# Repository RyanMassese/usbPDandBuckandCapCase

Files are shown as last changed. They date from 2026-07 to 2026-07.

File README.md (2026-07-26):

# USB-C PD + Buck Converter + Capacitor Case

3D-printable enclosure (STL) for a small USB-C-powered adjustable DC supply
built from:

| Component | Part | Envelope used |
|---|---|---|
| DC-DC buck module 3–40 V in / 1.5–35 V out | [Altronics Z6334](https://www.altronics.com.au/p/z6334-dc-dc-buck-module-3-40v-input/) (LM2596) | 43 × 21 × 14 mm |
| 1000 uF 50 V low-ESR electrolytic capacitor | [Altronics R6187](https://www.altronics.com.au/p/r6187-lelon-1000uf-50v-pcb-low-esr-electrolytic-capacitor/) | 17 mm dia × 33 mm |
| USB-C PD trigger board, selectable voltage | [Core Electronics CE08536](https://core-electronics.com.au/usb-c-pd-trigger-board-selectable-voltage.html) | 42 × 18 mm |

A second **storage variant** additionally holds a BP-511 dummy battery
(DC coupler, 55 × 38 × 21 mm) and ~2 m of coiled cable.

## Files

Compact (electronics only), external **60.8 × 68.3 × 23.3 mm**:

- `case_base.stl` — the box. Print as-is (flat bottom on the bed).
- `case_lid.stl` — the lid, modeled in its assembled orientation.
- `case_lid_print_orientation.stl` — same lid pre-flipped flat-top-down, ready to print.
- `case_assembly_preview.stl` — base + lid together, for visual checking only.

With storage section, external **148.6 × 68.3 × 31.3 mm** (two-part lid):

- `case_base_with_storage.stl` — the box.
- `case_lid_with_storage_electronics.stl` — screwed lid over the electronics
  section (3 × M3).
- `case_lid_with_storage_hatch.stl` — tool-free snap-fit hatch over the
  battery/cable storage section.
- `case_lid_with_storage_electronics_print_orientation.stl`,
  `case_lid_with_storage_hatch_print_orientation.stl` — pre-flipped to print.
- `case_assembly_with_storage_preview.stl` — visual check only.

Shared:

- `generate_case.py` — parametric generator; edit dimensions and re-run to regenerate everything.

## Layout

The lane order and orientation follow how the unit is actually soldered: the
capacitor **and** the output cable go straight onto the buck module's
OUT+/OUT− pads with short leads, and flying leads run from the PD board's
screw terminal to the buck's IN pads. So the buck sits IN-end-first beside the
PD board's terminal — a ~24 mm hop for the input pair — which puts OUT at the
USB-C end with the capacitor's lead end right beside it.

Three parallel bays separated by 10 mm divider walls. **Each divider stops
short at the end where soldered wires have to cross lanes**, so nothing has to
arch over a wall:

1. **PD trigger bay** (front) — board slides in against the end wall; a
   14 × 9.6 mm cutout in that wall accepts the USB-C plug overmold. An end
   stop holds the board with 0.5 mm play. A 26 × 10 mm window in the lid
   exposes the voltage-select button and its LED row. The last 14 mm of the
   lane past the board is left open as a loop zone for the input pair, and
   the PD/buck divider is cut away there.
2. **Buck module bay** (middle) — low corner stops locate the 43 × 21 mm
   board with its **IN end toward the loop zone**. Lid vent slots (3 mm wide)
   sit above it for cooling and double as screwdriver access, but set the
   output voltage with the trimpot **before** final assembly. The output
   cable leaves through an 8 mm slot in the OUT-end wall (open to the top
   edge), one lane over from the USB-C opening.
3. **Capacitor cradle** (back) — the 1000 uF cap lies on its side in two
   saddle ribs (17.5 mm dia opening) with its **lead end toward the buck's
   OUT end**, about 16 mm of lead path away. The buck/cap divider is cut away
   for the first 16 mm so the leads cross straight over.

Because the input and output both terminate at the buck's OUT end, the USB-C
socket and the DC output slot share the same end wall, ~25 mm apart. That is
forced by the wiring: putting the PD terminal next to the buck's IN end
necessarily puts the USB-C and the output at the other.

### Storage variant

The storage version is 26.5 mm deep inside (vs 18.5 mm): the BP-511 dummy is
~21 mm thick lying flat, and its cable enters through a hole in the dummy's
**top face**, so there is ~5.5 mm of headroom for the cable to bend over the
battery. The section sits right of the electronics, behind a full-height
wall:

The bays follow the cable's own order — it arrives from the electronics, gets
coiled, and ends at the dummy — so the coil bay comes first and the BP-511
sits at the outer end beside the slot it deploys through:

4. **Cable bay** — open 44 × 63.5 × 26.5 mm compartment (~74 cm³) for ~2 m of
   coiled cable, first thing past the section wall. Because the output cable
   is soldered at the buck's OUT end (the USB-C end), it runs back over the
   top of the buck module and through a **high** notch in that wall — there
   is 12.5 mm of headroom above the module in this variant.
5. **BP-511 pocket** — 40 × 56 mm pocket at the outer end, behind a 12 mm
   retaining rib. The rib is well under the dummy's 21 mm thickness, so its
   top-face cable simply passes over into the bay; the rib's 26 mm gap is
   finger access to lift the dummy out.
6. **Deployment slot** — an 8 mm slot in the outer end wall beside the stored
   dummy, at the opposite end of the case from the USB-C inlet. It is open to
   the top edge: with the hatch off, lift the dummy out over the wall, drop
   its cable into the slot, and snap the hatch back on with the unused length
   still coiled inside.

The lid is split in two at the section wall:

- **Electronics lid** — screwed down with the same 3 × M3 self-tappers as the
  compact case. You only open this for wiring changes.
- **Storage hatch** — no screws. A half-round snap ridge on each long edge of
  its lip clicks into matching grooves in the case walls (~0.25 mm
  engagement). Thumb notches in both wall top edges, centered on the storage
  section, let you push the hatch edge up to pop it off. Snap tightness is
  tuned via `SNAP_RIDGE_R` / `SNAP_GROOVE_R` in the script.

## Assembly

1. Print in PETG or PLA, 0.2 mm layers, 3 walls, no supports needed
   (the USB-C opening bridges 14 mm — any printer handles that).
2. Set the buck module's output voltage first, then drop the boards in.
   A dab of hot glue or double-sided tape under each board stops rattle.
3. Orientation matters — the bays are cut for one way round:
   - PD board: USB-C against the end wall, screw terminal facing in.
   - Buck module: **IN end away from the USB-C wall**, OUT end toward it.
   - Capacitor: **lead end toward the USB-C wall**, beside the buck's OUT
     pads (mind polarity — the stripe is negative).
4. The input pair crosses the cut-away PD/buck divider at the IN end; the
   cap leads and the output cable cross the cut-away buck/cap divider at the
   OUT end. Nothing needs to route over a divider.
5. Lid screws: 3 × M3 self-tapping (8–10 mm long) into the corner posts
   (2.7 mm pilot holes), countersunk heads sit flush.

## Regenerating / tweaking

```bash
pip install trimesh manifold3d shapely numpy
python3 generate_case.py
```

All dimensions (wall thickness, clearances, bay sizes, slot positions) are
named parameters at the top of `generate_case.py`.

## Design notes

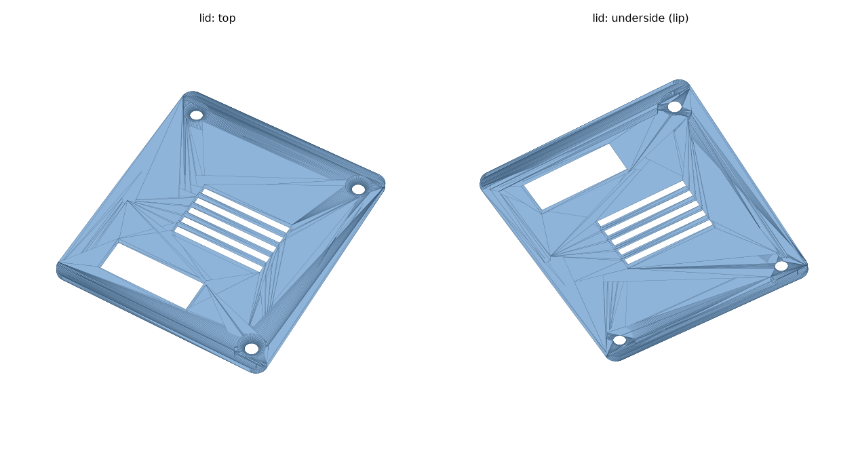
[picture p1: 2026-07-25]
preview_lid.png

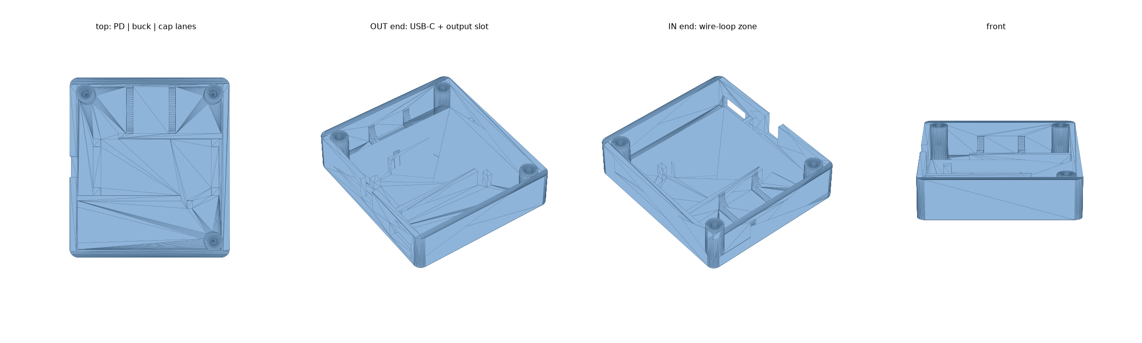
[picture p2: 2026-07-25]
preview_base.png

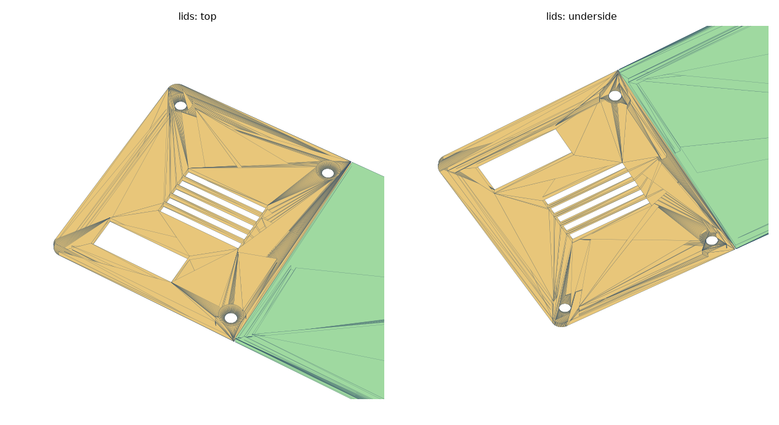
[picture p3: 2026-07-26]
preview_lid_with_storage.png

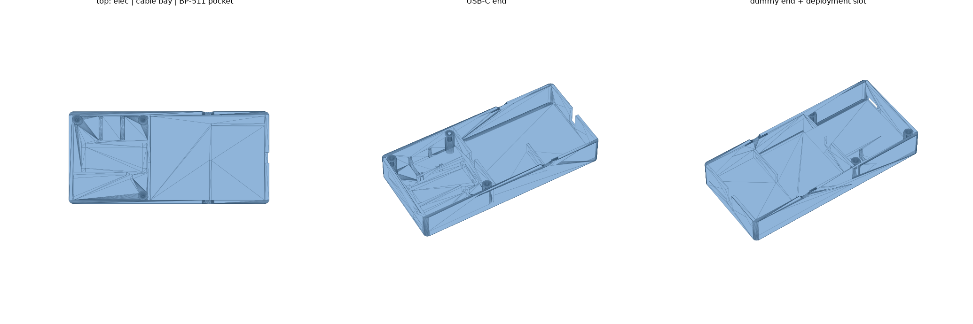
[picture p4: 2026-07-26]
preview_base_with_storage.png

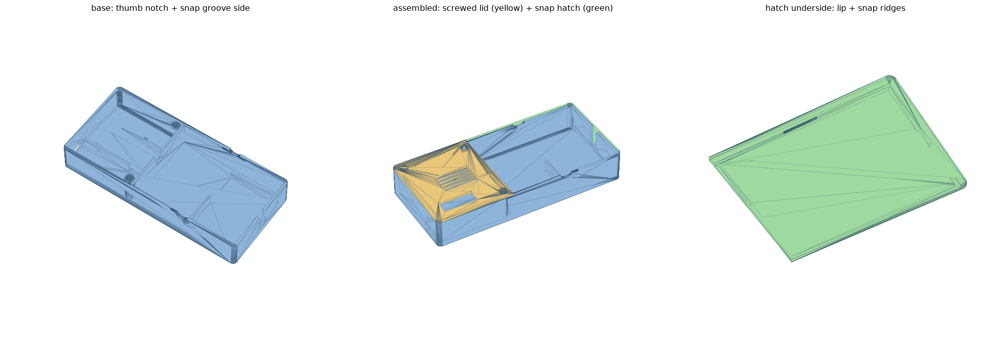
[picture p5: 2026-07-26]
preview_split_lid.png

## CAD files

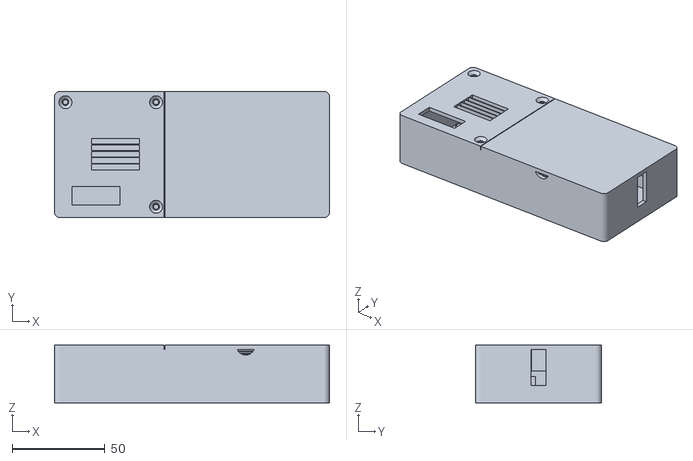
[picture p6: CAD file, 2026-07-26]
case_assembly_with_storage_preview.stl
148.6 x 68.3 x 31.3

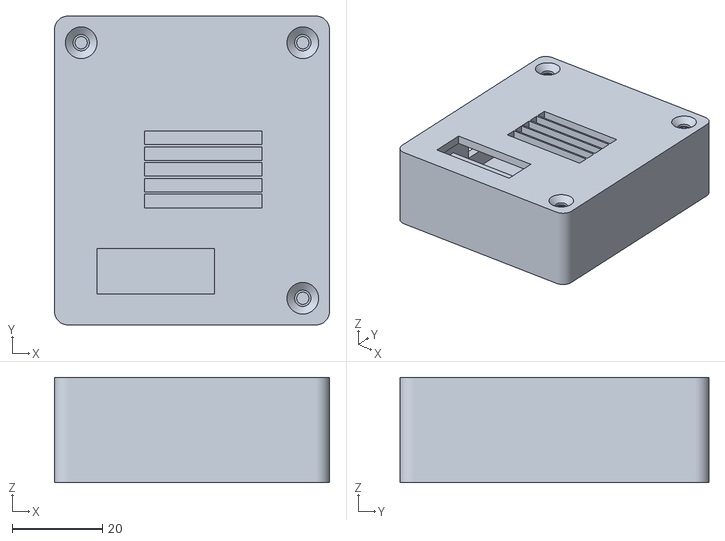
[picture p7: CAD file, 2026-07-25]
case_assembly_preview.stl
60.8 x 68.3 x 23.3

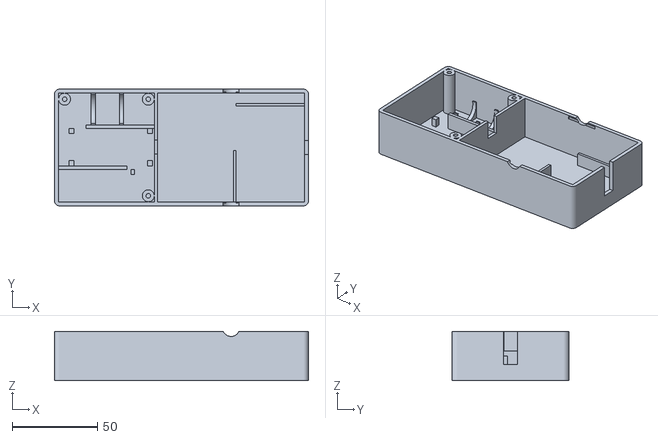
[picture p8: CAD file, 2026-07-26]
case_base_with_storage.stl
148.6 x 68.3 x 28.9

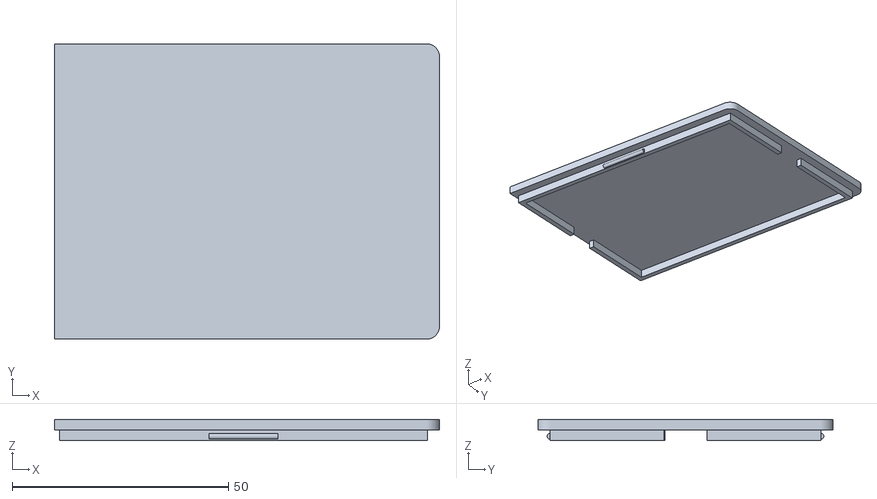
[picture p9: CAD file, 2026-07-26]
case_lid_with_storage_hatch.stl
89.0 x 68.3 x 4.90

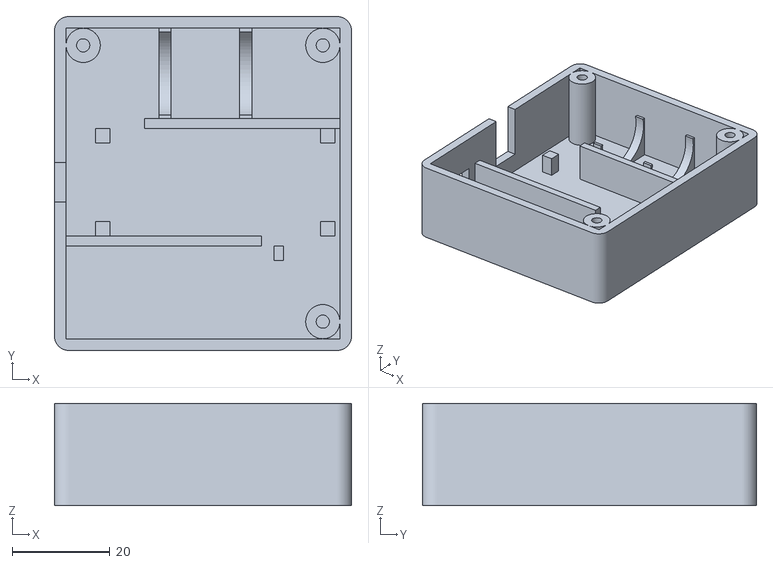
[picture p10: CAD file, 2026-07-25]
case_base.stl
60.8 x 68.3 x 20.9

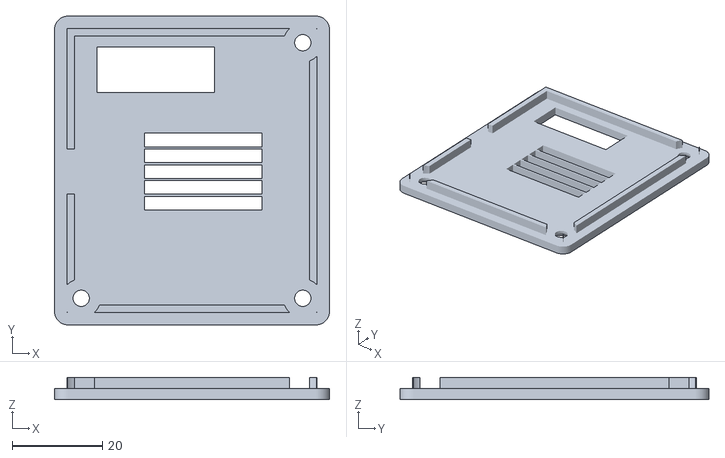
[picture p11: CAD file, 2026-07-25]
case_lid_print_orientation.stl
60.8 x 68.3 x 4.90

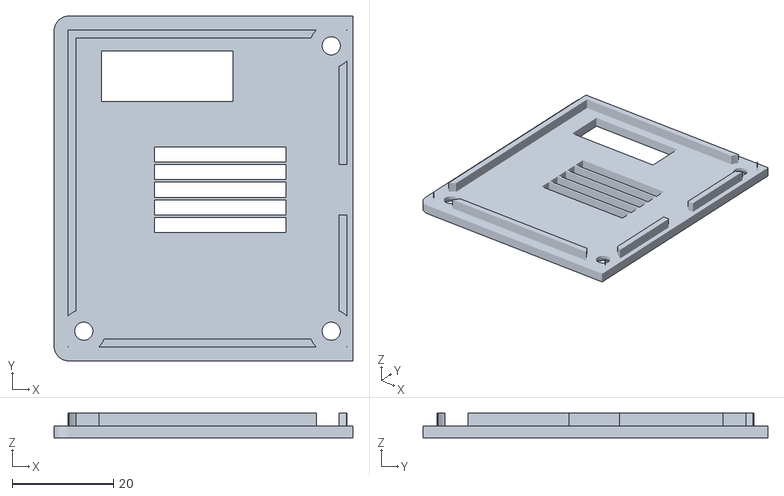
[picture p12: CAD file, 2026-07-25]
case_lid_with_storage_electronics_print_orientation.stl
59.2 x 68.3 x 4.90

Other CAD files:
case_lid_with_storage_hatch_print_orientation.stl
case_lid_with_storage_electronics.stl
case_lid.stl

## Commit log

2026-07-25 Add 3D-printable case for USB-C PD trigger, buck module and capacitor (#1)
    Parametric generator and STLs for two enclosure variants: compact electronics-only, and a version with a storage section for a BP-511 dummy battery and 2m of coiled cable.
    [case_assembly_preview.stl, case_assembly_with_storage_preview.stl, case_base.stl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]
2026-07-25 Split storage-variant lid: screwed electronics lid + snap-fit storage hatch
    The storage version's single 5-screw lid becomes two parts that split
    at the full-height section wall: the electronics side keeps the 3-screw
    lid (vents, button slot), while the storage side is a tool-free hatch.
    The hatch snaps in via half-round ridges on its lip engaging grooves in
    the front/back walls (~0.25mm interference), and thumb notches in both
    wall top edges give leverage to pop it off. Removes the two cable-bay
    screw posts and the superseded one-piece storage lid STLs.
    Claude-Session: https://claude.ai/code/session_01Ct7jFQnfVvAxKQCb3uBHvM
    [case_assembly_with_storage_preview.stl, case_base_with_storage.stl, case_lid_with_storage.stl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]
2026-07-25 Open up lid clearances around screw posts and holes
    The lid lip cutouts around the screw pillars had only 0.3mm clearance,
    which jams on real prints (posts print oversize, cutouts undersize).
    Post cutouts now get a dedicated 0.8mm/side clearance (POST_LIP_CLR),
    M3 clearance holes go 3.4->3.6mm, countersinks 6.4->7.0mm, and the
    general lip-to-wall fit relaxes 0.3->0.4mm. Snap ridge grows
    0.55->0.65mm to keep ~0.25mm engagement after the lip shift.
    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
    [case_assembly_preview.stl, case_assembly_with_storage_preview.stl, case_lid.stl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]
2026-07-25 Resize capacitor cradle for 17mm diameter cap (measured, was 13mm)
    Widens the cap lane 14.5->18.5mm, raises the saddle axis so the 8.75mm
    saddle cut clears the floor by 0.25mm instead of gouging through it,
    and grows the compact interior height 16->18.5mm so the cap top keeps
    ~1.3mm lid clearance. Both variants get 4mm wider (68.3mm); the
    storage variant's height is unchanged. Previews and README updated.
    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
    [case_assembly_preview.stl, case_assembly_with_storage_preview.stl, case_base.stl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]
2026-07-25 Fit 33mm capacitor and route the BP-511 dummy's top-face cable
    Measured part corrections from a test print: the cap body is 33mm long
    (ribs re-spaced to its quarter points) and the dummy battery's cable
    enters through a hole in its top face. Storage interior grows
    22->26.5mm for cable headroom above the battery, the retaining-rib gap
    moves to the cable end of the pocket, and a new 8mm deployment slot in
    the back wall lets the cable run straight out to the camera in use.
    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
    [case_assembly_preview.stl, case_assembly_with_storage_preview.stl, case_base.stl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]
2026-07-25 Lay out the electronics section to match the as-built wiring
    From the build photos the cap and the output cable are soldered straight
    onto the buck module's OUT pads with short leads, and flying leads run
    from the PD board's screw terminal to the buck's IN pads. The previous
    layout ignored that: the cap sat centred in its lane ~22mm from the OUT
    pads, and both 10mm dividers ran full length so every soldered wire had
    to arch over a wall.
    Now the buck is placed IN-end-first beside the PD terminal (24mm hop for
    the input pair), which puts OUT at the USB-C end with the cap's lead end
    16mm away; each divider is cut away 16mm at the end its wires cross;
    the section grows 50->56mm for a 14mm wire-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
    [case_assembly_preview.stl, case_assembly_with_storage_preview.stl, case_base.stl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]
2026-07-25 Swap the storage bays so they follow the cable's own order
    The output cable arrives from the electronics section, so it met the
    BP-511 pocket first and had to cross the stored dummy to reach the coil
    bay at the far end. Put the cable bay against the section wall and the
    dummy - which is on the cable's far end - at the outer end, next to the
    exit slot it deploys through. That also puts the DC output at the
    opposite end of the case from the USB-C inlet.
    Folds the redundant back-wall deployment slot into the end-wall exit
    slot, and drops the rib gap's cable-pass role: at 12mm the rib is well
    under the dummy's 21mm thickness, so the top-face cable clears it and
    the gap is just finger access.
    C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
    [case_assembly_with_storage_preview.stl, case_base_with_storage.stl, case_lid_with_storage_hatch.stl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]
2026-07-26 Grow the cable bay 30% (57 -> 74 cm3)
    Bay height is pinned by the battery pocket and its width by the case
    width, so the extra volume comes from length: 34 -> 44.2mm, taking the
    storage case from 138.4 to 148.6mm long.
    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
    [case_assembly_with_storage_preview.stl, case_base_with_storage.stl, case_lid_with_storage_hatch.stl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]
